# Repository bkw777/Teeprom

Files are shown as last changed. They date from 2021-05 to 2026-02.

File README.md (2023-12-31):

These are all virtual UV EPROMS / virtual mask roms, using electrically programmable EEPROM, FRAM, or FLASH with the pinout adapted to work in place of 27Cxx UV/OTP EPROMS or standard mask roms, on a specially shaped PCB and 3d-printed carrier to create a virtual Molex 78802 module to fit inside a Molex 78805 socket.

# Teeprom
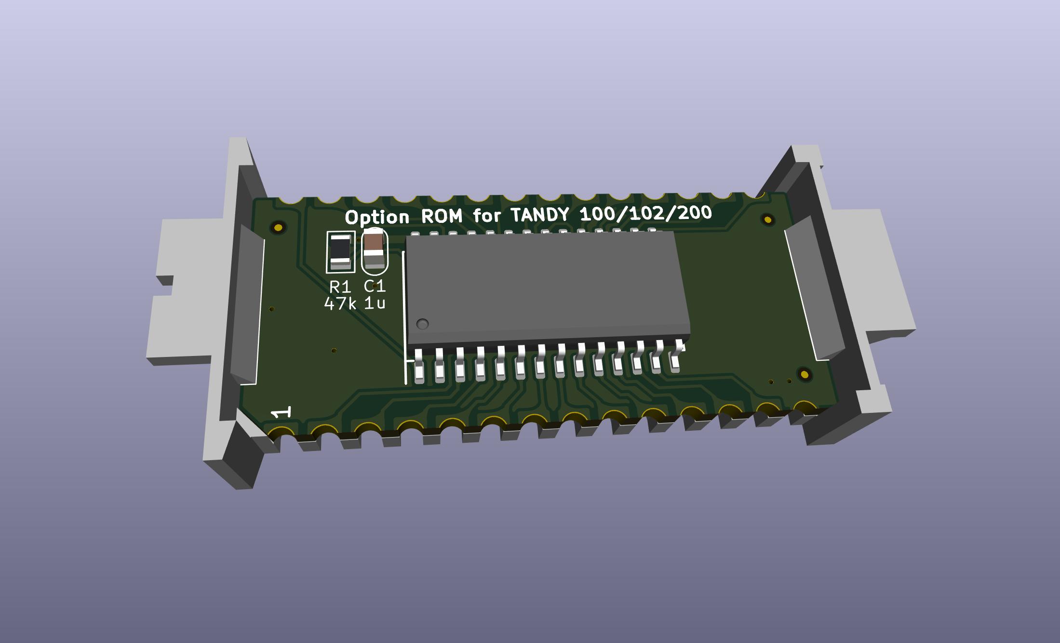
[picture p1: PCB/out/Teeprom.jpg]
Teeprom render


[Teeprom](http://tandy.wiki/Teeprom) is an EEPROM module for Tandy Model 100, 102, & 200 portable computers.

# Meeprom
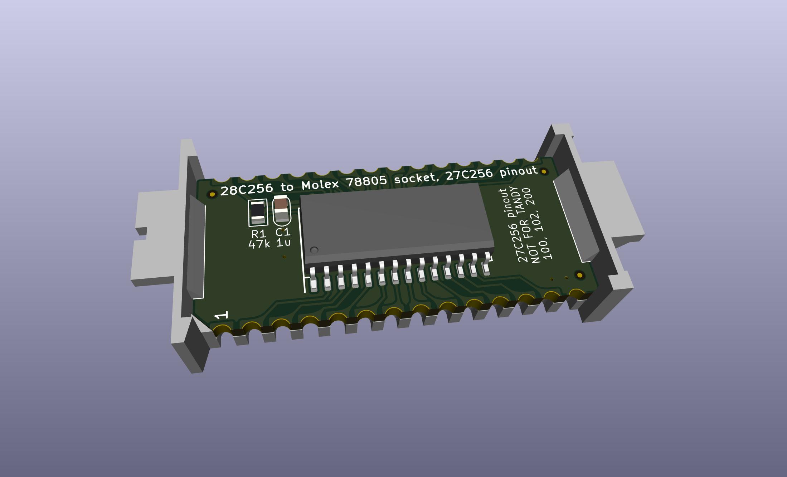
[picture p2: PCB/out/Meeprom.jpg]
Meeprom render


[Meeprom](http://tandy.wiki/Meeprom) is an EEPROM module for any other Molex 78805 socket that expects a 27C256 or standard mask rom chip. Not for Model 100/200. Examples: Tandy Model 600, Kyotronic KC-85, Epson PX-4, PX-8, handheld terminals like Intermec 9440, various industrial equipment like Allen Bradley SLC-500 PLCs, etc.

# MEE2732
Virtual 27C32 & virtual Molex 78802 carrier  
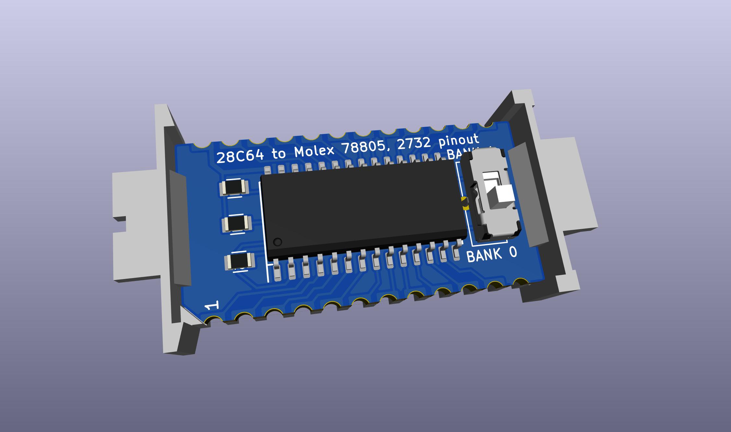
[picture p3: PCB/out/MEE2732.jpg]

[MEE2732](MEE2732.md)  
24-pin 2732 pinout

# M4ROM
[M4ROM](https://github.com/bkw777/M4ROM)  
Version of Teeprom & Meeprom that uses a 29F010 flash instead of a 28C256 eeprom, and provides 4 32k rom images.

# References
[Molex78802_Module](https://github.com/bkw777/Molex78802_Module)

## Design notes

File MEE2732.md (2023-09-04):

# MEE2732



24-pin with 2732 pinout.  
28C64 to provides 2 virtual 2732's.  
Programmable via SOIC-28 test clip.

PCB: [OSHPark](https://oshpark.com/shared_projects/sVU04x8d) or [PCBWAY](https://www.pcbway.com/project/shareproject/MEE2732___24_pin_Molex_78802_Virtual_2732_EEPROM.html)  
BOM: https://www.digikey.com/short/fjhhqq27  
Carrier: [Shapeways](http://shpws.me/SOvJ) or [Sculpteo](https://www.sculpteo.com/en/print/molex78802_pcb_24-4/xMikpkmg)

If you want a low-profile version where the switch does not stick out,  
replace the [CL-SB-12C-02](https://www.digikey.com/short/3zrp84cr) switch with [CL-SB-12C-12](https://www.digikey.com/short/b9djbwmq) .

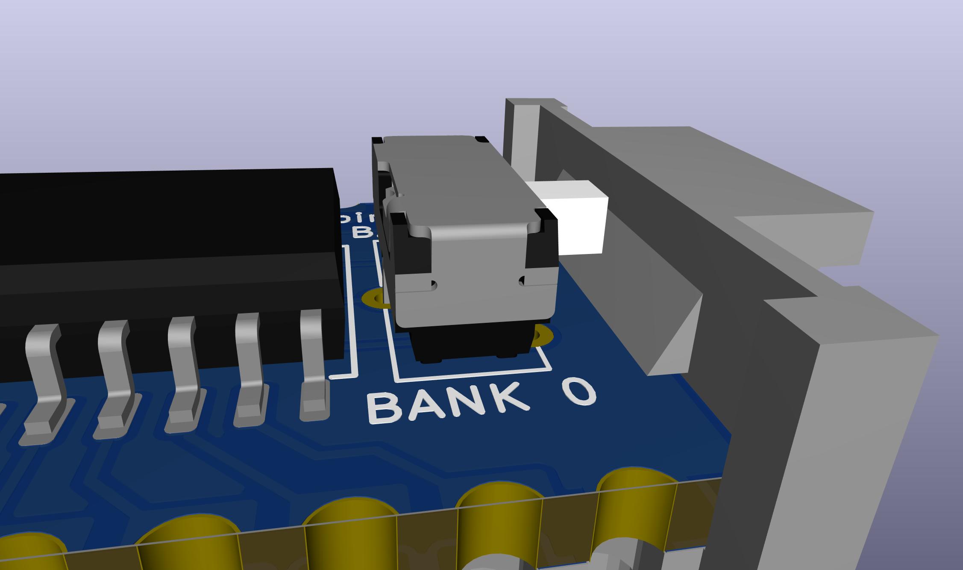
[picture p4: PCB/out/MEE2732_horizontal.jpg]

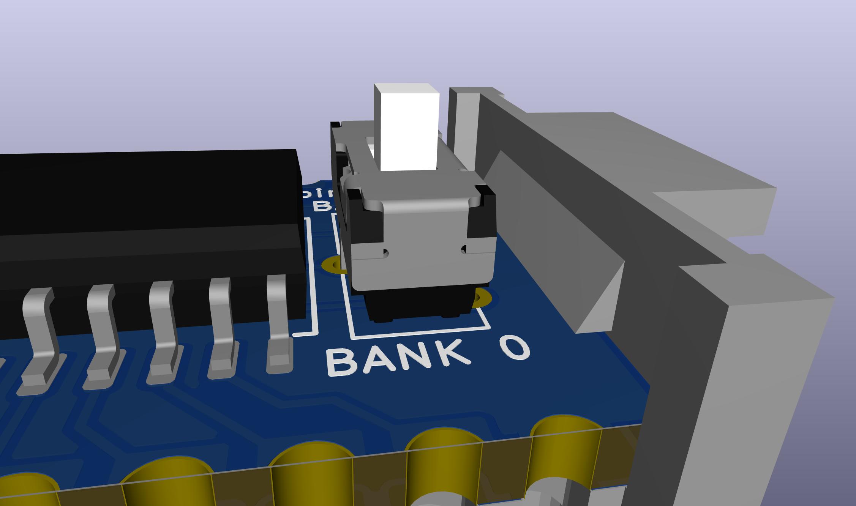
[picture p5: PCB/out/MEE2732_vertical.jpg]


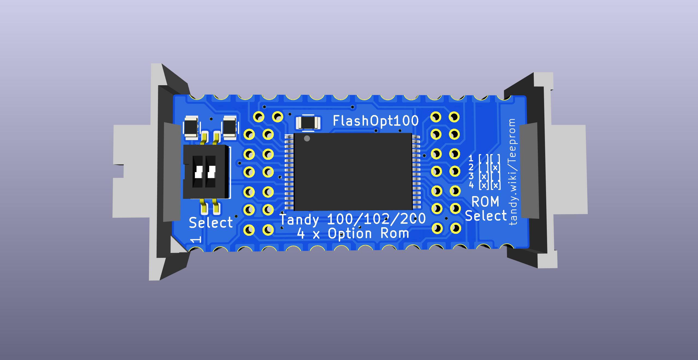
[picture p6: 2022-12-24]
FlashOpt100_1.jpg

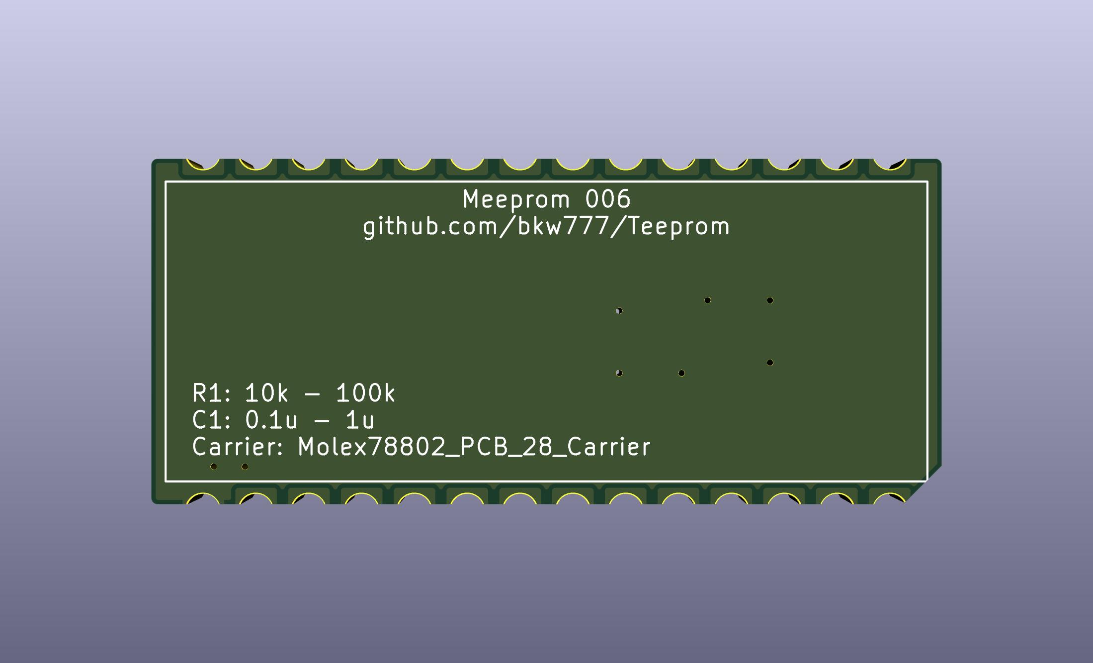
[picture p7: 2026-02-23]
PCB/out/Meeprom.bottom.jpg

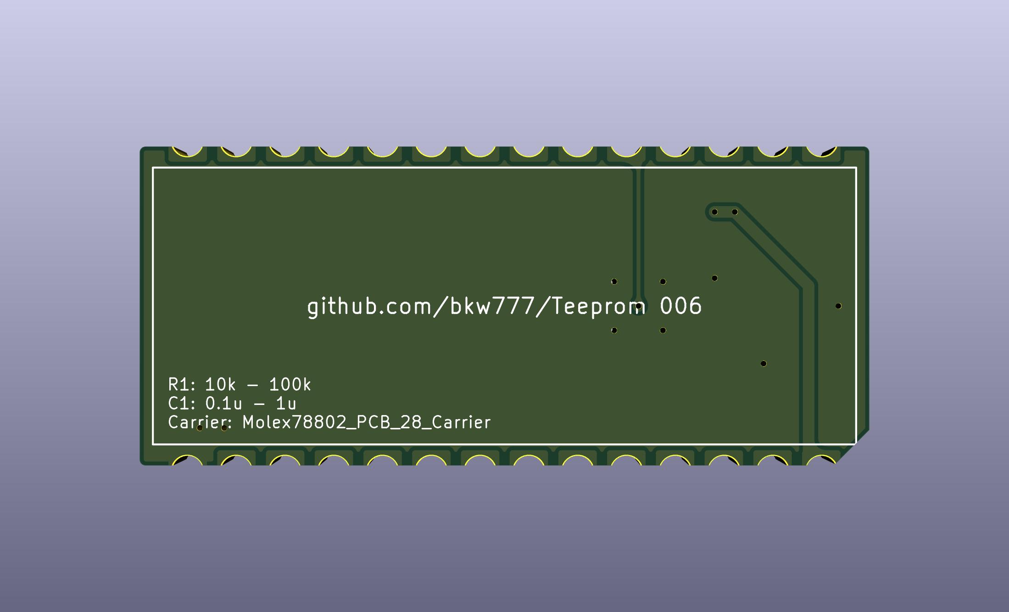
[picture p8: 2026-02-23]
PCB/out/Teeprom.bottom.jpg

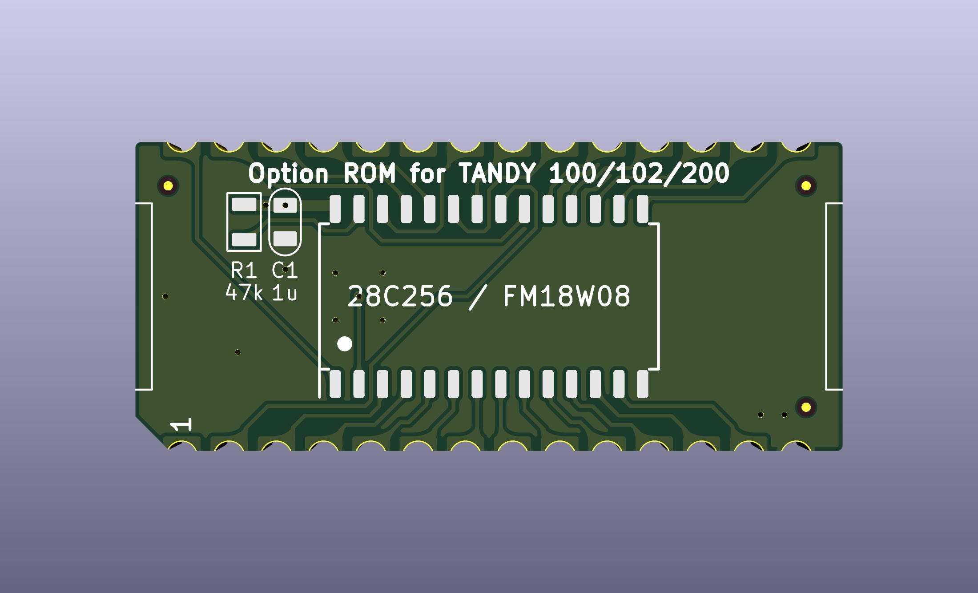
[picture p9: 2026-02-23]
PCB/out/Teeprom.top.jpg

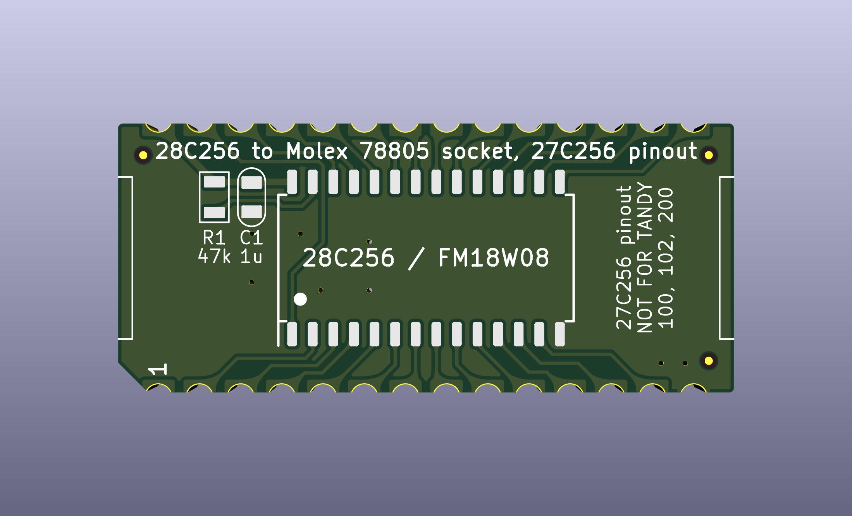
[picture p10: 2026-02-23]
PCB/out/Meeprom.top.jpg

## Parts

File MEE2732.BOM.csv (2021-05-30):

Index | Quantity | Part Number | Manufacturer Part Number | Description | Customer Reference | Available | Backorder | Unit Price | Extended Price USD
1 | 3 | A106052CT-ND | CRG0805F100K | RES SMD 100K OHM 1% 1/8W 0805 |  | 3 | 0 | 0.10000 | 0.30
2 | 1 | AT28C64B-15SU-TCT-ND | AT28C64B-15SU-T | IC EEPROM 64KBIT PARALLEL 28SOIC |  | 1 | 0 | 5.08000 | 5.08
3 | 1 | 563-1323-ND | CL-SB-12C-02 | SWITCH SLIDE SPDT 200MA 12V |  | 1 | 0 | 1.23000 | 1.23

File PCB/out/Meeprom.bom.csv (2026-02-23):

Reference | Qty | Value | DNP | Exclude from BOM | Exclude from Board | Footprint | Datasheet | MPN | Description
C1 | 1 | 1u |  |  |  | 000_LOCAL:C_0805 | datasheets/CL21B105KAFNNNE.pdf | CL21B105KAFNNNE | C 1u 0805
R1 | 1 | 47k |  |  |  | 000_LOCAL:R_0805 | datasheets/dcrcwe3.pdf | CRCW080547K0FKEA | R 47K 1% 0.25W 0805
U1 | 1 | 28C256 / FM18W08 |  |  |  | 000_LOCAL:SOIC-28W | datasheets/28C256.pdf | AT28C256-15SU | EEPROM 32Kx8 Parallel 5v 28-SOIC

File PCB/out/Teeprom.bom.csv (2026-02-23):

Reference | Qty | Value | DNP | Exclude from BOM | Exclude from Board | Footprint | Datasheet | MPN
C1 | 1 | 1u |  |  |  | 000_LOCAL:C_0805 | datasheets/CL21B105KAFNNNE.pdf | CL21B105KAFNNNE
R1 | 1 | 47k |  |  |  | 000_LOCAL:R_0805 | datasheets/dcrcwe3.pdf | CRCW080547K0FKEA
U1 | 1 | 28C256 / FM18W08 |  |  |  | 000_LOCAL:SOIC-28W | datasheets/28C256.pdf | AT28C256-15SU

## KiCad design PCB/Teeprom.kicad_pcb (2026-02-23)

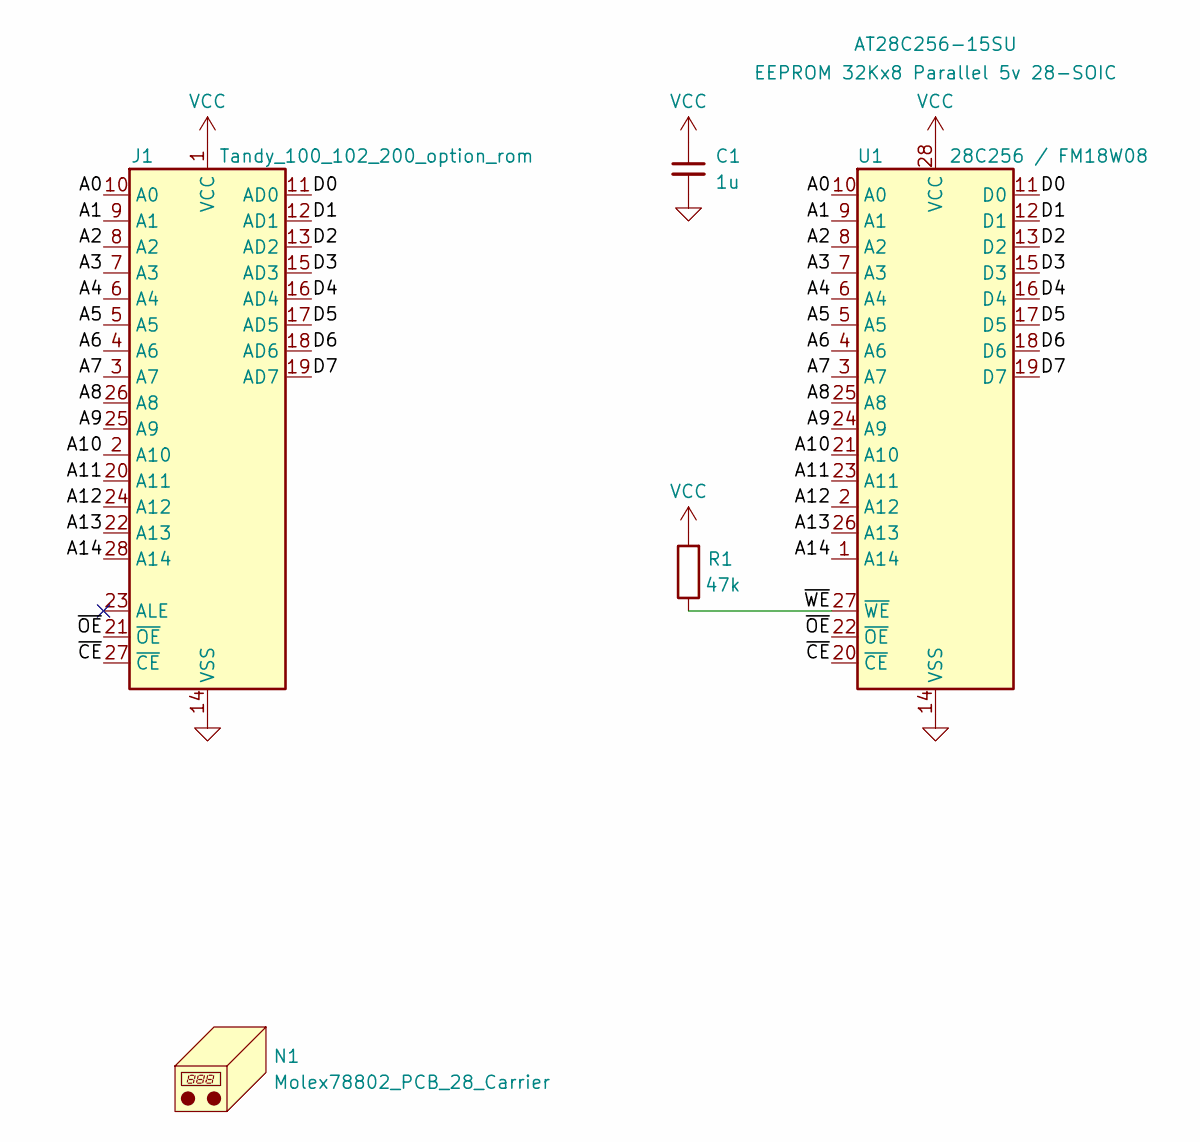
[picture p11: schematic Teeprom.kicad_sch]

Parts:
C1: 1u; C_0805; MPN CL21B105KAFNNNE
J1: Tandy_100_102_200_option_rom; Molex78802_PCB_28
N1: Molex78802_PCB_28_Carrier
R1: 47k; R_0805; MPN CRCW080547K0FKEA
U1: 28C256 / FM18W08; SOIC-28W; MPN AT28C256-15SU

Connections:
/A0: J1.10 (A0), U1.10 (A0)
/A1: J1.9 (A1), U1.9 (A1)
/A2: J1.8 (A2), U1.8 (A2)
/A3: J1.7 (A3), U1.7 (A3)
/A4: J1.6 (A4), U1.6 (A4)
/A5: J1.5 (A5), U1.5 (A5)
/A6: J1.4 (A6), U1.4 (A6)
/A7: J1.3 (A7), U1.3 (A7)
/A8: J1.26 (A8), U1.25 (A8)
/A9: J1.25 (A9), U1.24 (A9)
/A10: J1.2 (A10), U1.21 (A10)
/A11: J1.20 (A11), U1.23 (A11)
/A12: J1.24 (A12), U1.2 (A12)
/A13: J1.22 (A13), U1.26 (A13)
/A14: J1.28 (A14), U1.1 (A14)
/D0: J1.11 (AD0), U1.11 (D0)
/D1: J1.12 (AD1), U1.12 (D1)
/D2: J1.13 (AD2), U1.13 (D2)
/D3: J1.15 (AD3), U1.15 (D3)
/D4: J1.16 (AD4), U1.16 (D4)
/D5: J1.17 (AD5), U1.17 (D5)
/D6: J1.18 (AD6), U1.18 (D6)
/D7: J1.19 (AD7), U1.19 (D7)
/~CE: J1.27 (~CE), U1.20 (~CE)
/~OE: J1.21 (~OE), U1.22 (~OE)
/~WE: R1.1, U1.27 (~WE)
GND: C1.2, J1.14 (VSS), U1.14 (VSS)
VCC: C1.1, J1.1 (VCC), R1.2, U1.28 (VCC)

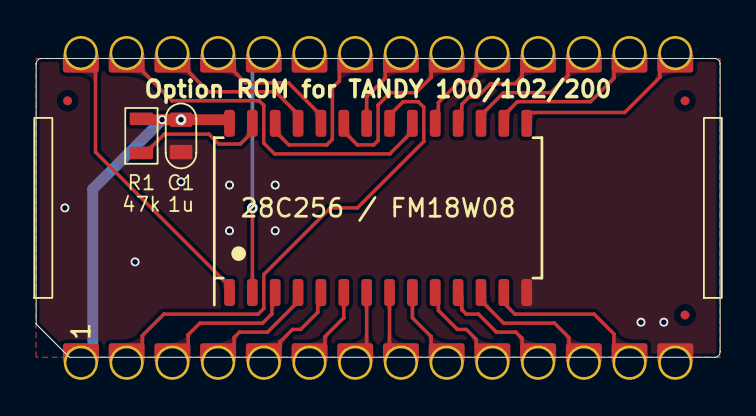
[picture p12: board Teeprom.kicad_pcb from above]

Board: 2 copper layers, 38.0 x 16.6 mm, 5 parts (0 on the bottom side), 28 nets.

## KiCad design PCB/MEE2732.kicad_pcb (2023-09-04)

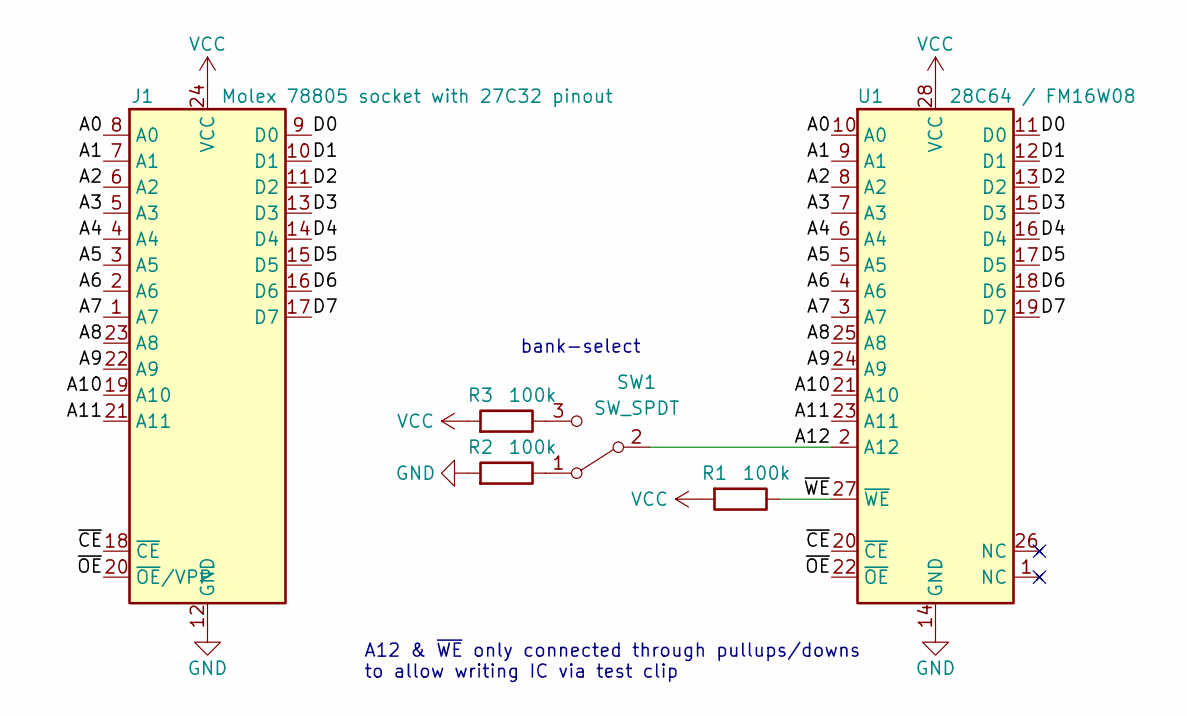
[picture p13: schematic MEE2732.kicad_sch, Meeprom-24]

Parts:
J1: Molex 78805 socket with 27C32 pinout; Molex78802_PCB_24
R1, R2, R3: 100k; R_0805
SW1: SW_SPDT; CL-SB-12C-0x
U1: 28C64 / FM16W08; SOIC-28W

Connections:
/A0: J1.8 (A0), U1.10 (A0)
/A1: J1.7 (A1), U1.9 (A1)
/A2: J1.6 (A2), U1.8 (A2)
/A3: J1.5 (A3), U1.7 (A3)
/A4: J1.4 (A4), U1.6 (A4)
/A5: J1.3 (A5), U1.5 (A5)
/A6: J1.2 (A6), U1.4 (A6)
/A7: J1.1 (A7), U1.3 (A7)
/A8: J1.23 (A8), U1.25 (A8)
/A9: J1.22 (A9), U1.24 (A9)
/A10: J1.19 (A10), U1.21 (A10)
/A11: J1.21 (A11), U1.23 (A11)
/A12: SW1.2 (B), U1.2 (A12)
/D0: J1.9 (D0), U1.11 (D0)
/D1: J1.10 (D1), U1.12 (D1)
/D2: J1.11 (D2), U1.13 (D2)
/D3: J1.13 (D3), U1.15 (D3)
/D4: J1.14 (D4), U1.16 (D4)
/D5: J1.15 (D5), U1.17 (D5)
/D6: J1.16 (D6), U1.18 (D6)
/D7: J1.17 (D7), U1.19 (D7)
/~CE: J1.18 (~CE), U1.20 (~CE)
/~OE: J1.20 (~OE/VPP), U1.22 (~OE)
/~WE: R1.1, U1.27 (~WE)
GND: J1.12 (GND), R2.2, U1.14 (GND)
unnamed: R2.1, SW1.1 (A)
unnamed: R3.1, SW1.3 (C)
VCC: J1.24 (VCC), R1.2, R3.2, U1.28 (VCC)

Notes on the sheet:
bank-select
A12 & ~{WE} only connected through pullups/downs to allow writing IC via test clip

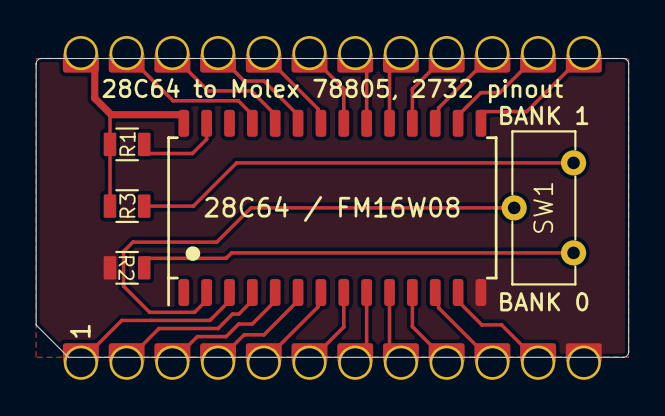
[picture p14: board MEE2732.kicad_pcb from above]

Board: 2 copper layers, 32.9 x 16.6 mm, 6 parts (0 on the bottom side), 28 nets.

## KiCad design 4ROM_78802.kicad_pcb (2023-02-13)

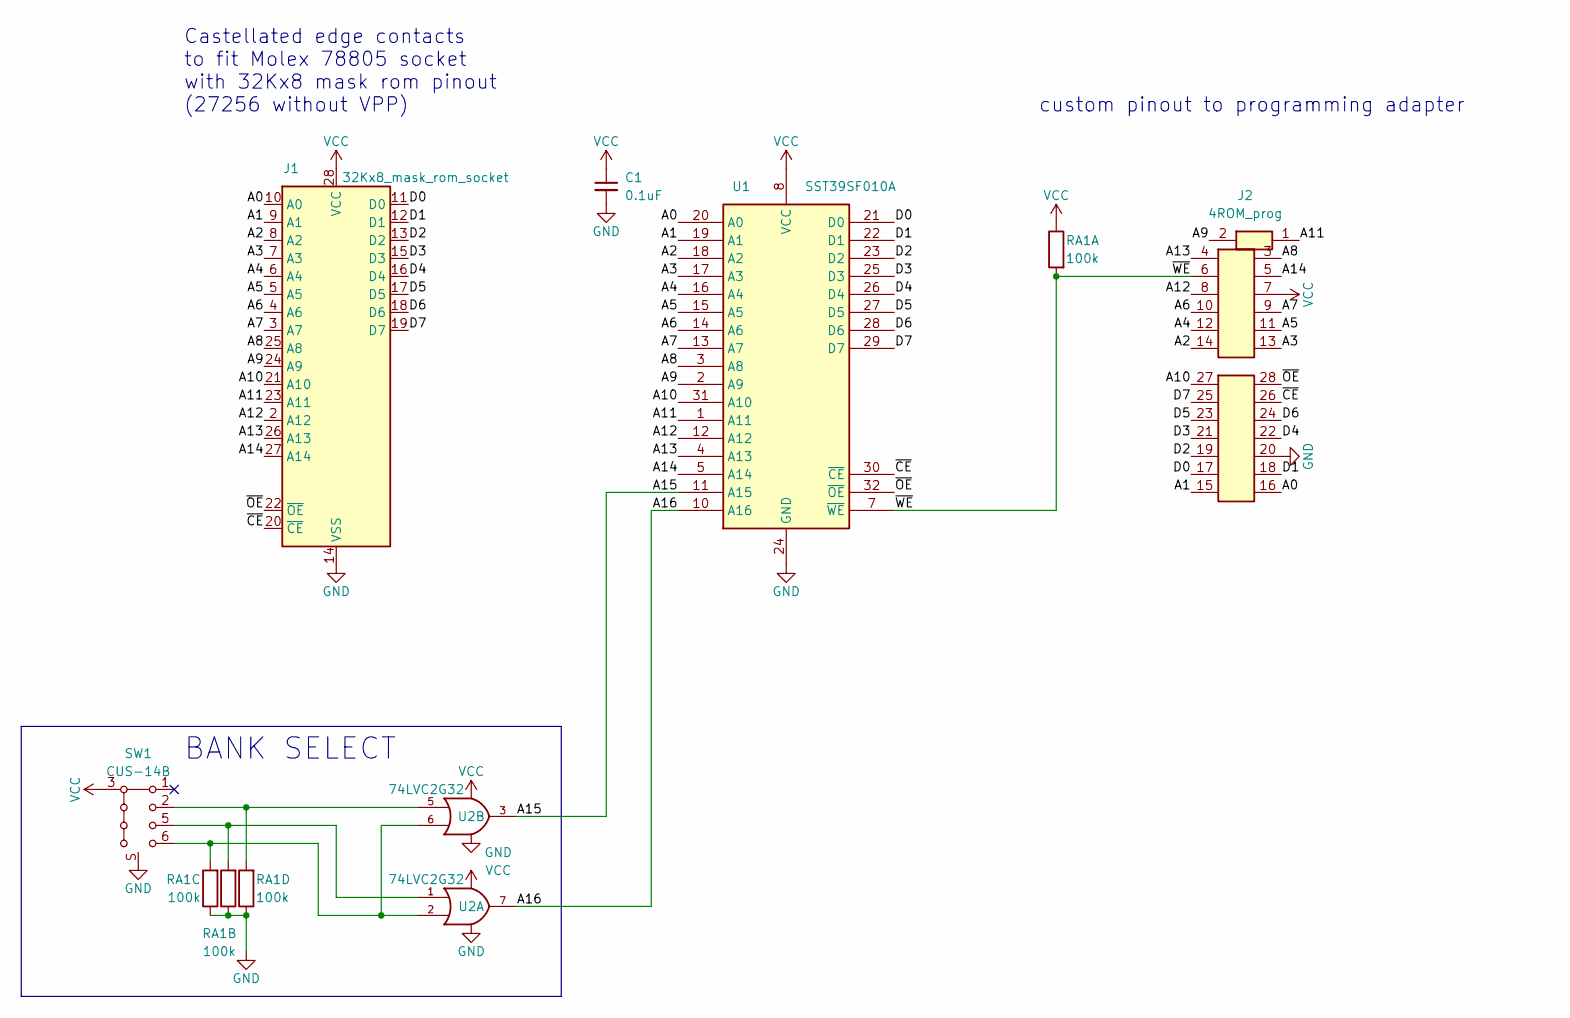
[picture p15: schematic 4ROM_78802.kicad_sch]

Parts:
C1: 0.1uF; C_0805
J1: 32Kx8_mask_rom_socket; Molex78802_PCB_28
J2: 4ROM_prog; 4ROM_prog_female
RA1: 100k; R_Array_Convex_4x0612
SW1: CUS-14B; SW_SP4T_CUS-14B
U1: SST39SF010A; TSOP32-14mm
U2: 74LVC2G32; TSSOP-8_3x3mm_P0.65mm

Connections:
/A0: J1.10 (A0), J2.16 (A0), U1.20 (A0)
/A1: J1.9 (A1), J2.15 (A1), U1.19 (A1)
/A2: J1.8 (A2), J2.14 (A2), U1.18 (A2)
/A3: J1.7 (A3), J2.13 (A3), U1.17 (A3)
/A4: J1.6 (A4), J2.12 (A4), U1.16 (A4)
/A5: J1.5 (A5), J2.11 (A5), U1.15 (A5)
/A6: J1.4 (A6), J2.10 (A6), U1.14 (A6)
/A7: J1.3 (A7), J2.9 (A7), U1.13 (A7)
/A8: J1.25 (A8), J2.3 (A8), U1.3 (A8)
/A9: J1.24 (A9), J2.2 (A9), U1.2 (A9)
/A10: J1.21 (A10), J2.27 (A10), U1.31 (A10)
/A11: J1.23 (A11), J2.1 (A11), U1.1 (A11)
/A12: J1.2 (A12), J2.8 (A12), U1.12 (A12)
/A13: J1.26 (A13), J2.4 (A13), U1.4 (A13)
/A14: J1.27 (A14), J2.5 (A14), U1.5 (A14)
/A15: U1.11 (A15), U2.3
/A16: U1.10 (A16), U2.7
/D0: J1.11 (D0), J2.17 (D0), U1.21 (D0)
/D1: J1.12 (D1), J2.18 (D1), U1.22 (D1)
/D2: J1.13 (D2), J2.19 (D2), U1.23 (D2)
/D3: J1.15 (D3), J2.21 (D3), U1.25 (D3)
/D4: J1.16 (D4), J2.22 (D4), U1.26 (D4)
/D5: J1.17 (D5), J2.23 (D5), U1.27 (D5)
/D6: J1.18 (D6), J2.24 (D6), U1.28 (D6)
/D7: J1.19 (D7), J2.25 (D7), U1.29 (D7)
/~CE: J1.20 (~CE), J2.26 (~CE), U1.30 (~CE)
/~OE: J1.22 (~OE), J2.28 (~OE), U1.32 (~OE)
/~WE: J2.6 (~WE), RA1.1 (R1.1), U1.7 (~WE)
GND: C1.2, J1.14 (VSS), J2.20 (GND), RA1.5 (R4.2), RA1.6 (R3.2), RA1.7 (R2.2), SW1.S, U1.24 (GND), U2.4 (GND)
unnamed: RA1.2 (R2.1), SW1.5, U2.1
unnamed: RA1.3 (R3.1), SW1.6, U2.2, U2.6
unnamed: RA1.4 (R4.1), SW1.2, U2.5
VCC: C1.1, J1.28 (VCC), J2.7 (VCC), RA1.8 (R1.2), SW1.3 (C), SW1.4 (C), U1.8 (VCC), U2.8 (VCC)

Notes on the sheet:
Castellated edge contacts to fit Molex 78805 socket with 32Kx8 mask rom pinout (27256 without VPP)
custom pinout to programming adapter
BANK SELECT

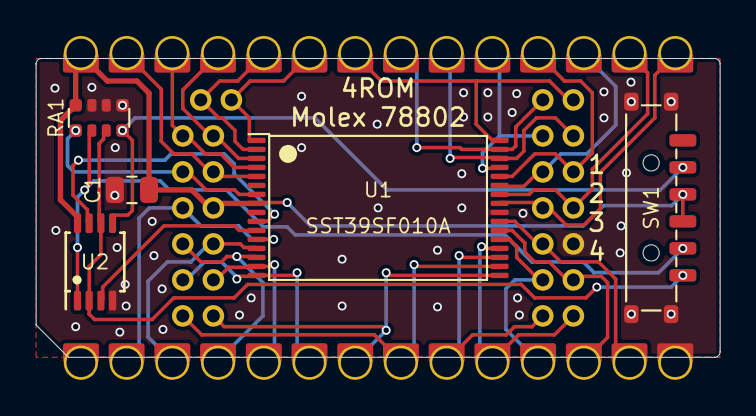
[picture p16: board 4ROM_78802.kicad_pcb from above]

Board: 2 copper layers, 38.0 x 16.6 mm, 7 parts (0 on the bottom side), 33 nets.

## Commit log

2019-09-09 update to new pcb2molex8878 template & carrier with chamfer instead of pin
    [Teeprom.kicad_pcb]
2020-02-29 update to latest pcb2molex8878 pcb dimensions and carrier model
2020-03-08 Change license to CC. Add Meeprom. Add copper pours.
    [Meeprom.kicad_pcb, Meeprom.sch]
2020-03-08 improve pour
    [Teeprom.kicad_pcb]
2020-03-08 improve ground paths in pours
    [Meeprom.kicad_pcb, Teeprom.kicad_pcb]
2020-03-10 lock virtual footprint for carrier, set page title
    [Meeprom.kicad_pcb, Meeprom.sch, Teeprom.kicad_pcb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]
2020-10-06 gitignore, remove explicit gnd trace
    [Meeprom.kicad_pcb, Teeprom.kicad_pcb]
2020-10-23 Teeprom 2.0 the overkilling (new board FlashOpt100)
    [FlashOpt100.kicad_pcb, FlashOpt100.sch]
2020-10-23 remove sharp inside angle vcc & r1
    [FlashOpt100.kicad_pcb]
2020-10-23 FlashRom100 programming socket
    [FlashOpt100.kicad_pcb]
2020-10-23 FlashOpt100 programming port
    [FlashOpt100.kicad_pcb, FlashOpt100.sch]
2020-10-23 programming adapter
    [FlashOpt100.kicad_pcb, FlashOpt100_programming_adapter.kicad_pcb, FlashOpt100_programming_adapter.sch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]
2020-11-01 flashopt100 prg holes alignment, prg adapter dip holes size
    [FlashOpt100.kicad_pcb, FlashOpt100_programming_adapter.kicad_pcb]
2020-11-01 flashopt100 prg routing & text
    [FlashOpt100.kicad_pcb, FlashOpt100_programming_adapter.kicad_pcb]
2020-11-08 adjust some footprints and remove flashopt100 programming adapter from readme
    [FlashOpt100.kicad_pcb]
2020-11-09 completely new FlashOpt100 and programming adapter
    [FlashOpt100.kicad_pcb, FlashOpt100.sch, FlashOpt100_programming_adapter.kicad_pcb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]
2020-11-09 FlashOpt100 remove zone fill
    [FlashOpt100.kicad_pcb, FlashOpt100_programming_adapter.kicad_pcb]
2021-05-23 cleanup files
    [Meeprom.sch]
2021-05-23 update to v004 board outline and carrier
    [FlashOpt100.kicad_pcb, FlashOpt100.sch, Meeprom.kicad_pcb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]
2021-05-30 add MEE2732
    [MEE2732.BOM.csv, MEE2732.kicad_pcb, MEE2732.sch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]
2021-05-30 spurious leftover trace on Meeprom
    [Meeprom.kicad_pcb]
2022-12-24 kicad 6, flashopt100 programming socket
    [FlashOpt100.kicad_pcb, FlashOpt100.kicad_sch, FlashOpt100.sch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]
2022-12-24 MEE2732 minor tidy up
    [MEE2732.kicad_pcb]
2023-01-10 add FRAM to silkscreen, rename FlashOpt100 to 4ROM_100, fix 4ROM programming adapter, add 4ROM_STD
    [4ROM_100.BOM.csv, 4ROM_100.kicad_pcb, 4ROM_100.kicad_sch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]
2023-02-13 4ROM_78802 and programming adapter are now tested and verified
    [4ROM_100.kicad_pcb, 4ROM_100.kicad_sch, 4ROM_78802.kicad_pcb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]
2023-02-13 4ROM_78802 and 4ROM programming adapter BOM & PCB links
2023-02-21 4ROM_100 pcb url
2023-02-26 cosmetic schematic touchups
    [4ROM_100.kicad_sch, 4ROM_78802.kicad_sch]
2023-09-04 kicad 7, renders, reoganize files
    [4ROM_100.kicad_pcb, 4ROM_100.kicad_sch, 4ROM_78802.kicad_pcb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]
2023-12-31 split off 4ROM to it's own repo
    [4ROM_100.BOM.csv, 4ROM_100.kicad_pcb, 4ROM_100.kicad_sch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]
2026-02-23 add caps & fiducials, remove dead shapeways links
    [Meeprom.kicad_pcb, Meeprom.kicad_sch, Teeprom.bom.csv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]

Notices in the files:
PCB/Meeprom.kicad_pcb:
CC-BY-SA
